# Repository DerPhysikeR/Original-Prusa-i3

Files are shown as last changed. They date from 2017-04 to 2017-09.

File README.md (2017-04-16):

# Replikeo Prusa i3 MK2S (Alpha: Not finished yet!)

This is an adaptation of the printed parts of the original Prusa i3 MK2S, to work with the parts included in the Prusa i3 kit from Replikeo.

Some parts like a new heated bed and an E3D V6 have to to be bought.

**Links**

 * Prusa Research website : http://prusa3d.com
 * Product page : http://shop.prusa3d.com/en/3d-printers/59-original-prusa-i3-mk2-kit.html
 * Build manual : http://manual.prusa3d.com/c/Original_Prusa_i3_MK2S_kit_assembly
 * Firmware : https://github.com/prusa3d/Prusa-Firmware

# Printing Instructions

Supports need for:
 - x-idler
 - y-corners

y-idler: Infill 100% or it will crack

More instructions will follow.

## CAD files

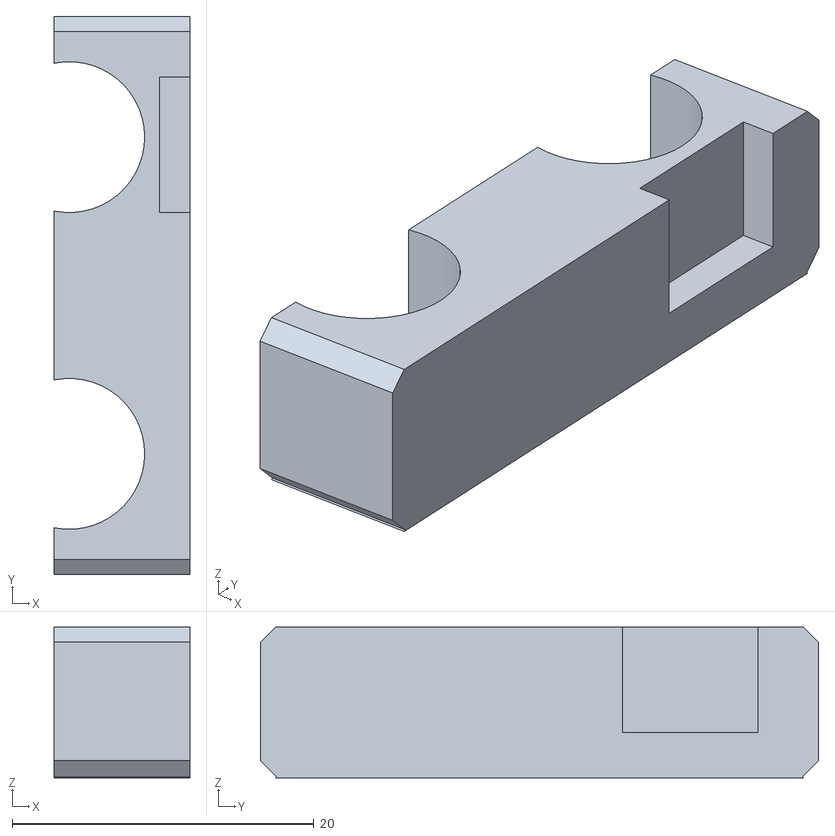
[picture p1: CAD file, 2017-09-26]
Printed-Parts/stl/Y-distance.stl
9.00 x 37.0 x 10.0

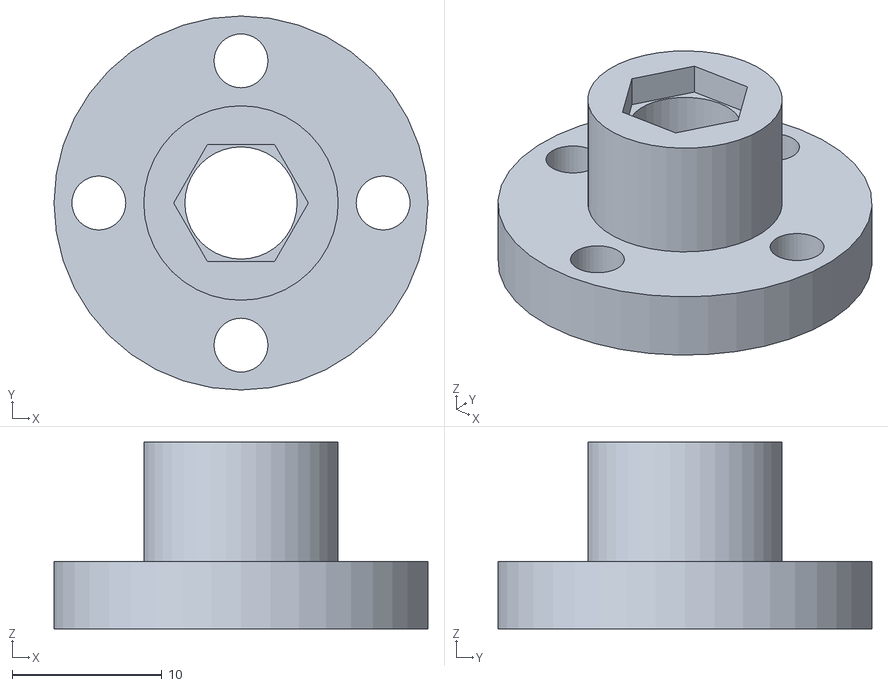
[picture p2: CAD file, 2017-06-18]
Printed-Parts/stl/z-axis-threaded-rod-adapter.stl
25.0 x 25.0 x 12.5

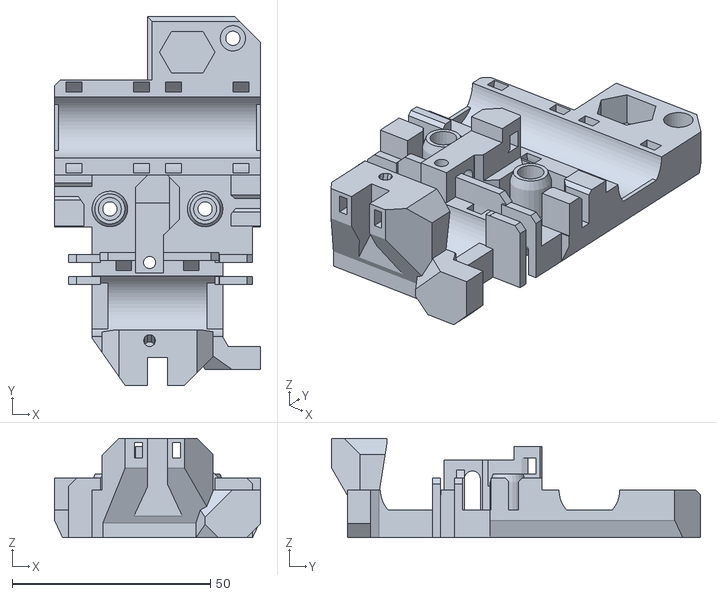
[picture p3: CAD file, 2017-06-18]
Printed-Parts/stl/x-carriage.stl
52.0 x 93.0 x 25.0

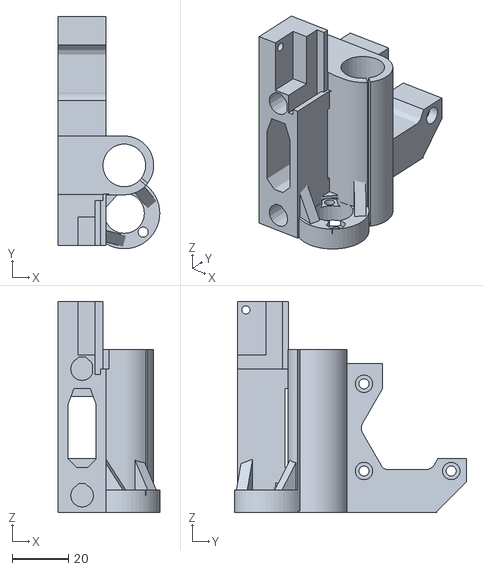
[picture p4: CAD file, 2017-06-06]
Printed-Parts/stl/x-end-motor.stl
36.1 x 82.6 x 75.0

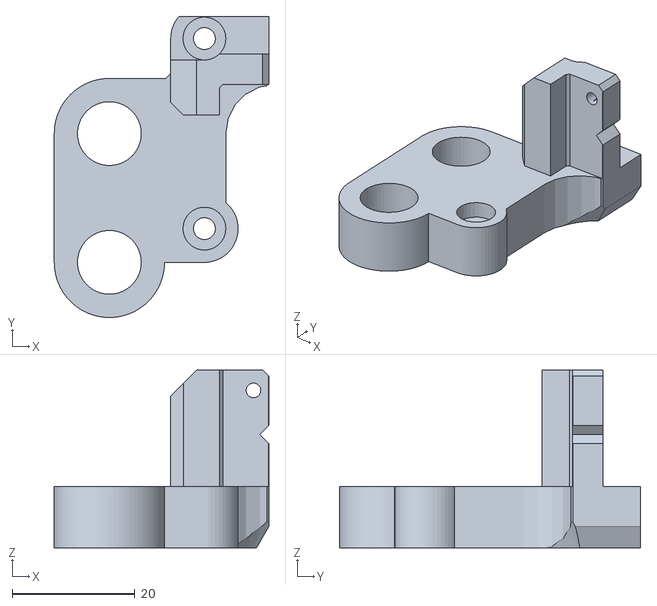
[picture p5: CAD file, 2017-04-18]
Printed-Parts/stl/y-motor.stl
35.0 x 49.1 x 29.0

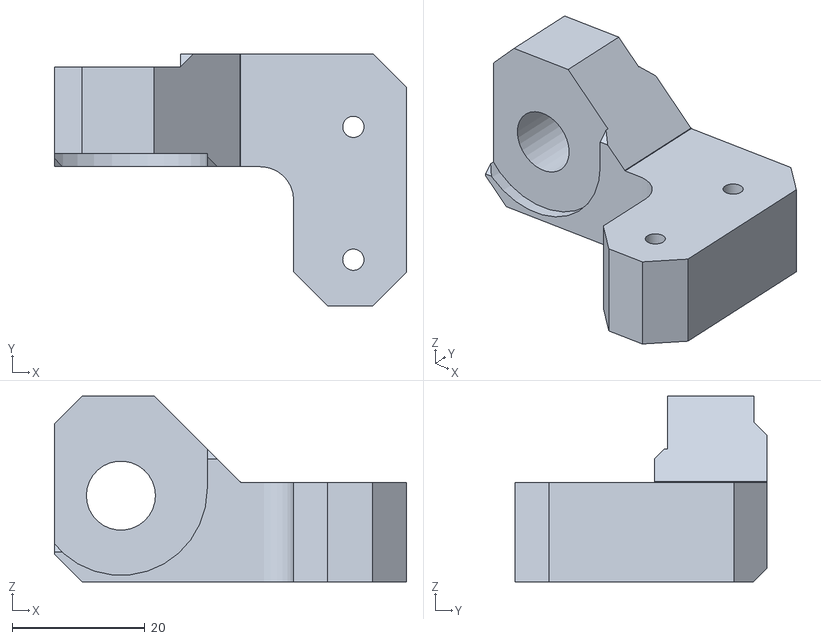
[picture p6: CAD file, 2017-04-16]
Printed-Parts/stl/PSU-Y-part.stl
53.0 x 38.0 x 28.0

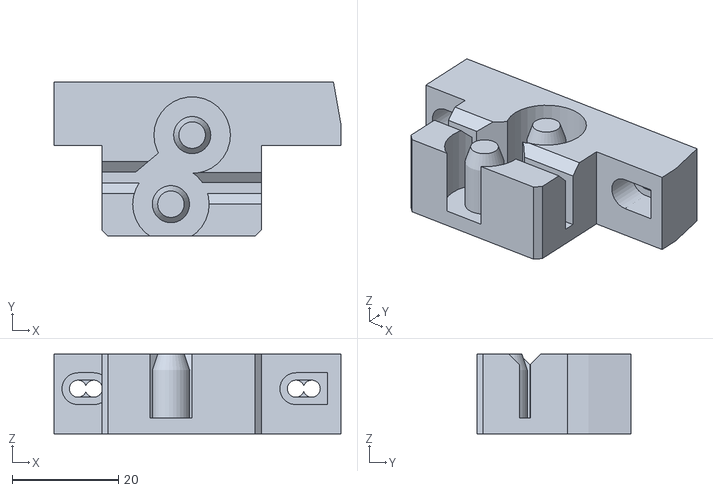
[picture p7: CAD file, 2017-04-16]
Printed-Parts/stl/y-belt-holder.stl
54.0 x 29.0 x 15.0

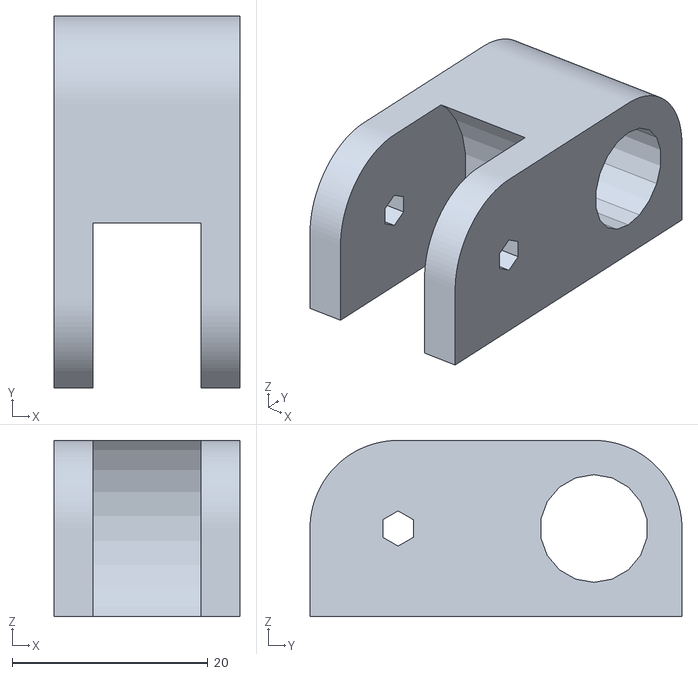
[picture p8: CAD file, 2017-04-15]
Printed-Parts/stl/y-idler.stl
19.0 x 38.0 x 18.0

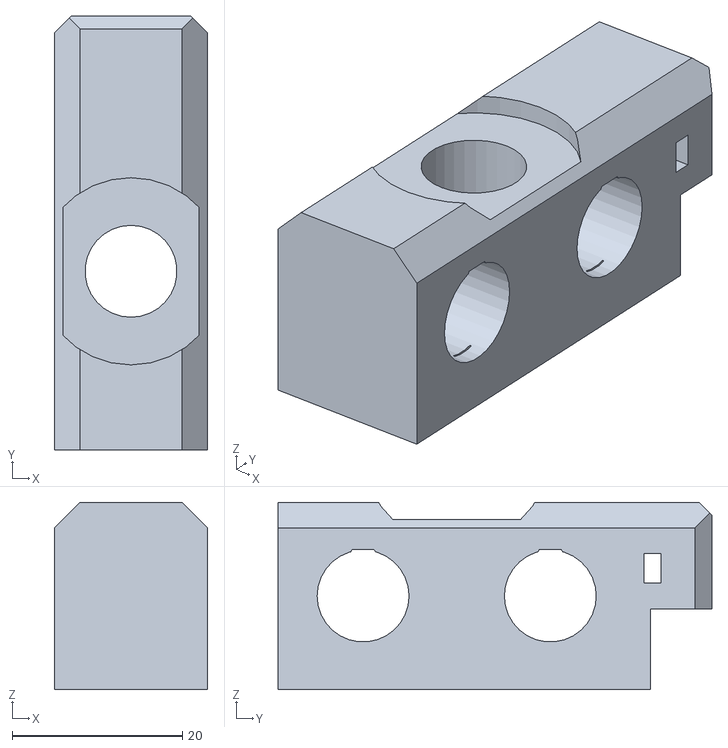
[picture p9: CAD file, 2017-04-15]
Printed-Parts/stl/y-corners.stl
18.0 x 51.0 x 22.0

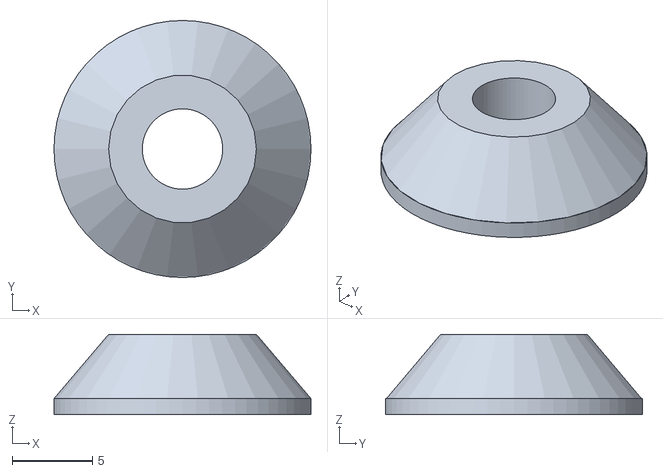
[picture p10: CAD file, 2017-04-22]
Printed-Parts/stl/z-screw-cover.stl
16.0 x 16.0 x 5.00

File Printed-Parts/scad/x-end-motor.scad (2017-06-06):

// PRUSA iteration3
// X end motor
// GNU GPL v3
// Josef Průša <iam@josefprusa.cz> and contributors
// http://www.reprap.org/wiki/Prusa_Mendel
// http://prusamendel.org

use <x-end.scad>

module x_end_motor_base(){
 x_end_base();
 translate(v=[-15,31,26.5]) cube(size = [17,44,53], center = true);
}

module x_end_motor_endstop_base(){
    translate([-23.5,-28.5,58]){
        difference(){
            // Base block
            cube([17,18.2,17]);
            // Nice edge
            /* translate([-1,5,20])rotate([-60,0,0])cube(30,30,30); */
            } 
        }
}

module support() {
     translate([-23.5,-28.5,49]){
          translate([13,0,0]) {
               translate([-.8,0,0]) cube([.8,16.1,5]);
          }
     }

}

module x_end_cutout() {
     translate([-23.5,-28.5,49]){
               translate([13,0,0]) {
                    translate([3,0,2]) cube([2,18.3,27]);
                    cube([2,16.1,27]);
                    translate([0,0,2]) cube([3,16.1,27]);
                    /* 13 is the real height of the endstop, but to make it printable a second cube with 20 is used */
                    translate([-5.9,0,7]) cube([7.9,10.1,13]);
                    translate([-5.9,0,7]) cube([7.9,10.1,20]);
                    /* translate([-20,0,23]) rotate([0, 90, 0]) cylinder(h=30, d=2.8, $fn=50); */
                    translate([-20,3,23]) rotate([0, 90, 0]) cylinder(h=30, d=3, $fn=10);
                    }
          }

}

module x_end_motor_endstop_holes(){
    translate([-23.5,-28.5,58]){
        translate([17/2,7.5,-3]){
            // Back screw hole for endstop
            translate([-4.75,0,0])cylinder(r=1,h=19,$fn=20);
            translate([-4.75,0,6])cylinder(r1=1, r2=1.5, h=2,$fn=20);
            // Front screw hole for endstop
            translate([4.75,0,0])cylinder(r=1,h=19,$fn=20);
            translate([4.75,0,6])cylinder(r1=1, r2=1.5, h=2,$fn=20);
            }
        }
}



module x_end_motor_holes(){
 x_end_holes();
 // Position to place
 translate(v=[-1,32,30.25]){
  // Belt hole
  translate(v=[-14,1,0]) cube(size = [10,46,22], center = true);
  // Motor mounting holes
  translate(v=[20,-15.5,-15.5]) rotate(a=[0,-90,0]) rotate(a=[0,0,90]) cylinder(h = 70, r=1.8, $fn=30);
  translate(v=[1,-15.5,-15.5]) rotate(a=[0,-90,0]) rotate(a=[0,0,90]) cylinder(h = 10, r=3.1, $fn=30);
  translate(v=[20,-15.5,15.5]) rotate(a=[0,-90,0]) rotate(a=[0,0,90]) cylinder(h = 70, r=1.8, $fn=30);
  translate(v=[1,-15.5,15.5]) rotate(a=[0,-90,0]) rotate(a=[0,0,90]) cylinder(h = 10, r=3.1, $fn=30);
  translate(v=[20,15.5,-15.5]) rotate(a=[0,-90,0]) rotate(a=[0,0,90]) cylinder(h = 70, r=1.8, $fn=30);
  translate(v=[1,15.5,-15.5]) rotate(a=[0,-90,0]) rotate(a=[0,0,90]) cylinder(h = 10, r=3.1, $fn=30);
  translate(v=[20,15.5,15.5]) rotate(a=[0,-90,0]) rotate(a=[0,0,90]) cylinder(h = 70, r=1.8, $fn=30);
  translate(v=[1,15.5,15.5]) rotate(a=[0,-90,0]) rotate(a=[0,0,90]) cylinder(h = 10, r=3.1, $fn=30);

  // Material saving cutout 
  translate(v=[-10,12,10]) cube(size = [60,42,42], center = true);

  // Material saving cutout
  translate(v=[-10,40,-30]) rotate(a=[45,0,0])  cube(size = [60,42,42], center = true);
  
 }
}

// Motor shaft cutout
module x_end_motor_shaft_cutout(){
    union(){
    difference(){
        translate(v=[0,32,30]) rotate(a=[0,-90,0]) rotate(a=[0,0,90]) cylinder(h = 70, r=17, $fn=6);
       
        translate(v=[-10,-17+32,30]) cube(size = [60,2,10], center = true);
        translate(v=[-10,-8+32,-15.5+30]) rotate(a=[60,0,0]) cube(size = [60,2,10], center = true); 
        translate(v=[-10,8+32,-15.5+30]) rotate(a=[-60,0,0]) cube(size = [60,2,10], center = true);
        
        
    }
    translate(v=[-30,25.2,-11.8 +30]) rotate(a=[0,90,0]) cylinder(h = 30, r=3, $fn=30);
    translate(v=[-30,19.05,30]) rotate(a=[0,90,0]) cylinder(h = 30, r=3.5, $fn=100);
}
}



module selective_infill()mirror([0,1,0]) translate([-50, -33, 0.6])
{ 
   difference()
    {
    union()
    {
        difference()
        {
        translate([50,50,0.6]) rotate([0,0,90]) cylinder( h=6, r=11.7, $fn=30);//0, 17, 0.6
        translate([50,50,-1]) rotate([0,0,90]) cylinder( h=10, r=11.5, $fn=30);
        }
        difference()
        {
        translate([50,50,0.6]) rotate([0,0,90]) cylinder( h=6, r=10.7, $fn=30); //0, 17, 0.6
        translate([50,50,-1]) rotate([0,0,90]) cylinder( h=10, r=10.5, $fn=30);
        } 
        difference()
        {
        translate([50,50,0.6]) rotate([0,0,90]) cylinder( h=6, r=9.9, $fn=30); //0, 17, 0.6
        translate([50,50,-1]) rotate([0,0,90]) cylinder( h=10, r=9.7, $fn=30);
        } 
        difference()
        {
        translate([50,50,0.6]) rotate([0,0,90]) cylinder( h=6, r=9, $fn=30); //0, 17, 0.6
        translate([50,50,-1]) rotate([0,0,90]) cylinder( h=10, r=8.8, $fn=30);
        } 
    }
    translate([57.5,50.5,-1]) rotate([0,0,45]) cube([8,10,9]); // front
    translate([52,30.5,-1]) rotate([0,0,45]) cube([10,20,20]);  // front angled
    translate([32,35.5,-1]) cube([8,30,9]); // inner horizontal
    }
   } 
   
 module reinforcement_selective_infill()
   {
    rotate([90,0,-15,]) translate ([-1.5, 8, 26])linear_extrude(height = 0.2) polygon( points=[[-2,0],[0,12],[8,0]] ); //bearings
    
    rotate([90,0,-50,]) translate ([8.5, 8, 1.4])linear_extrude(height = 0.2) polygon( points=[[0,0],[0,12],[8,0]] ); //body
    
    }
    
   
// Final part
module x_end_motor(){
 difference(){
     union(){
            x_end_motor_base();
            x_end_motor_endstop_base();
            
         }
  x_end_motor_shaft_cutout();
  x_end_motor_holes();
  /* x_end_motor_endstop_holes();       */
  x_end_cutout();
  selective_infill();
  reinforcement_selective_infill();
         
      /* translate([-12,-42,65]) rotate([-35,0,0])  rotate([0,0,45]) cube(10,10,10); */
      translate([-15,8.5,6]) rotate([90,0,0]) cylinder(h=5, r=5, $fn=30);   
      translate([-15,8.5,51]) rotate([90,0,0]) cylinder(h=5, r=5, $fn=30);   
      translate([-15,3.5,6]) rotate([90,0,0]) cylinder(h=3, r1=5, r2=4, $fn=30);   
      translate([-15,3.5,51]) rotate([90,0,0]) cylinder(h=3, r1=5, r2=4, $fn=30); 
 }
}

union() {
  x_end_motor();
  support();
}

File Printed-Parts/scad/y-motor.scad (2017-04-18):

// PRUSA iteration3
// Y motor mount
// GNU GPL v3
// Josef Průša <iam@josefprusa.cz> and contributors
// http://www.reprap.org/wiki/Prusa_Mendel
// http://prusamendel.org

//include <configuration.scad>

module y_motor_base() {
  union() {
    // Motor holding part
    translate(v = [29,-21+50,0]) {
      difference() {
        union() {
          translate(v = [-21+4.5,0,5]) cube(size = [9,31,10], center=true);
          translate(v = [-15.5,-15.5,0]) cylinder(h = 10, r=5.5, $fn=50);
          translate(v = [-15.5,+15.5,0]) cylinder(h = 10, r=5.5, $fn=50);
          translate([-21,7,0]) rotate([0,0,45]) cube([2, 2, 10]);

          //end stop
          /* translate(v = [-10.5,+15.5,0]) cylinder(h = 12, r=5.5, $fn=50); */
          translate([-12,0,0]) cube([7, 15, 10]);
          translate([-16,15,0]) cube([11, 4.1, 10]); //top of endstop mount //here
          translate([-21+6,8,0]) cube([12-2, 5, 29]);
          translate([-21,8-5,0]) cube([8, 10, 29]);
          translate([-21+9.5-2,7,0]) rotate([0,0,45]) cube([2, 2, 29]);
          // Joins motor holder and rod plate
          translate(v = [-31,-21,0]) cube(size = [16,30,10]);
        }
          //selective infill
          translate([-14.5,5,0.3]) cube([0.1,5.5,27]);
          translate([-16.5,5,0.3]) cube([0.1,5.5,27]);
          translate([-18.5,5,0.3]) cube([0.1,5.5,25]);
          translate([-10,9,1]) cube([0.1,3,26.3]);
          translate([-8,9,6]) cube([0.1,3,21.3]);
      }
    }
  }
  // Front holding part
  hull() {
    translate(v = [-2,8,0]) cylinder(h = 10, r=9, $fn=80);
    translate(v = [-2,29,0]) cylinder(h = 10, r=9, $fn=80);
  }
}

module y_motor_holes() {
  translate(v = [29,-21+50,0]) {
    // Screw head holes
    translate(v = [-15.5,-15.5,-1]) cylinder(h = 10, r=1.8, $fn=20);
    translate(v = [-15.5,+15.5,-1]) cylinder(h = 10, r=1.8, $fn=20);
    // Clearance for motor neck
    translate(v = [0,0,-1]) cylinder(h = 6, d1=24.2, d2=18.2, $fn=50);
    // Screw holes
    translate(v = [-15.5,-15.5,7]) cylinder(h = 7, r=3.5, $fn=30);
    translate(v = [-15.5,+15.5,7]) cylinder(h = 25, r=3.5, $fn=30);
  }

  translate(v = [-2,8,-1]) cylinder(h = 12, r=5.2, $fn=50);
  translate(v = [-2,29,-1]) cylinder(h = 12, r=5.2, $fn=50);

  //endstop
  translate([25,29,0])  cylinder(h = 29, r=8, $fn=20);

  /* M3 core diameter~=2.4mm */
  /* hole distance from front edge=3.1 */
  fed = 2.5;
  side_dist = -3.3 + 10;
  height_difference = 5.9;
  translate([24-fed,45+height_difference,side_dist]) rotate([90,0,0]) cylinder(h = 10, r=1.2, $fn=20);
  translate([24-fed,42.2+height_difference,side_dist]) rotate([90,0,0]) cylinder(h = 2, r1=1.7, r2=1.2, $fn=20);

  /* center distance endstop holes=19mm */
  cdist = 19;
  translate([24-fed,45,side_dist+cdist]) rotate([90,0,0]) cylinder(h = 10, r=1.2, $fn=20);
  translate([24-fed,42.2,side_dist+cdist]) rotate([90,0,0]) cylinder(h = 2, r1=1.7, r2=1.2, $fn=20);
  /* side distance for first hole = 3.7 */

  // endstop corner cutout
  translate([-10,30,28]) rotate([0,45,0]) cube([15, 19, 20]);
  translate([-1,41,10])  cube([15, 5, 19]);
  translate([27,33,0]) rotate([0,0,45]) cube([5, 5, 28]);
  translate([7,28,10.01]) rotate([0,0,45]) cube([5, 5, 28]);

  translate([22,32,0]) rotate([0,30,0]) cube([8, 20, 18]);
  translate([24.5-2,32,18.5]) rotate([0,45,0]) cube([3, 20, 3]);

  translate([23,32,29]) rotate([0,45,0]) cube([5, 20, 5]);

  // cut off top of end-stop mount
  translate([0,48.1,0]) cube([100,100,100]);
}

// Final part
module y_motor() {
  difference() {
    y_motor_base();
    y_motor_holes();
  }
}

y_motor();

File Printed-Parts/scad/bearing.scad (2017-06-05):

// PRUSA iteration3
// Bearing holders
// GNU GPL v3
// Josef Průša <iam@josefprusa.cz> and contributors
// http://www.reprap.org/wiki/Prusa_Mendel
// http://prusamendel.org

use <polyholes.scad>

bearing_diameter = 14.90;

module horizontal_bearing_base(bearings=1){
 translate(v=[0,0,6]) cube(size = [24,8+bearings*25,12], center = true);	
}
module horizontal_bearing_holes(bearings=1){
 cutter_lenght = 10+bearings*25;
 one_holder_lenght = 8+25;
 holder_lenght = 8+bearings*25;
 
 // Main bearing cut
 difference(){
  translate(v=[0,0,12]) rotate(a=[90,0,0]) translate(v=[0,0,-cutter_lenght/2]) cylinder(h = cutter_lenght, r=(bearing_diameter/2)+0.2, $fn=50);
  // Bearing retainers
  translate(v=[0,1-holder_lenght/2,3]) cube(size = [24,6,8], center = true);
  translate(v=[0,-1+holder_lenght/2,3]) cube(size = [24,6,8], center = true);
 }
 
 // Ziptie cutouts
 ziptie_cut_ofset = 0;
 for ( i = [0 : bearings-1] ){
  // For easier positioning I move them by half of one 
  // bearing holder then add each bearign lenght and then center again
  translate(v=[0,-holder_lenght/2,0]) translate(v=[0,one_holder_lenght/2+i*25,0]) difference(){
   union(){
    translate(v=[0,2-8.5,12]) rotate(a=[90,0,0]) translate(v=[0,0,0]) cylinder(h = 4, r=11.5, $fn=50);
    translate(v=[0,2+8.5,12]) rotate(a=[90,0,0]) translate(v=[0,0,0]) cylinder(h = 4, r=11.5, $fn=50);
   }
   translate(v=[0,12,12]) rotate(a=[90,0,0]) translate(v=[0,0,0]) cylinder(h = 24, r=9, $fn=50);
  }
 }
 
}

module horizontal_bearing_test(){
 difference(){
  horizontal_bearing_base(1);
  horizontal_bearing_holes(1);
 }
 translate(v=[30,0,0]) difference(){
  horizontal_bearing_base(2);
  #horizontal_bearing_holes(2);
 }
 translate(v=[60,0,0]) difference(){
  horizontal_bearing_base(3);
  horizontal_bearing_holes(3);
 }
}



thinwall = 3;
bearing_size = bearing_diameter + 2 * thinwall;

module vertical_bearing_base(){
 translate(v=[-2-bearing_size/4,0,29]) cube(size = [4+bearing_size/2,bearing_size,58], center = true);
 cylinder(h = 58, r=bearing_size/2, $fn = 90);
}

module vertical_bearing_holes(){
  translate(v=[0,0,-1]) poly_cylinder(h = 62, r=(bearing_diameter/2));
  translate(v=[0,0,-0.1]) cylinder(r1=(bearing_diameter/2)+0.7,r2=(bearing_diameter/2), h=0.5);
  rotate(a=[0,0,-40]) translate(v=[bearing_diameter/2-2.9,-0.5,0.5]) cube(size = [thinwall*2,1,62]);

}

//difference(){
//vertical_bearing_base();
vertical_bearing_holes();
//}
//horizontal_bearing_test();
//horizontal_bearing_base(1);
//horizontal_bearing_holes(1);

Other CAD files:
Printed-Parts/scad/PSU-Y-part.scad
Printed-Parts/scad/Y-distance.scad
Printed-Parts/scad/x-carriage.scad
Printed-Parts/scad/y-belt-holder.scad
Printed-Parts/scad/y-corners.scad
Printed-Parts/scad/y-idler.scad
Printed-Parts/scad/z-axis-threaded-rod-adapter.scad
Printed-Parts/scad/z-screw-cover.scad

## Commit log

2017-04-15 Adapted y-corners to 10mm threaded rods
    [y-corners.scad]
2017-04-15 Formatting in `y-corners`
    [y-corners.scad]
2017-04-15 Updated y-corners.stl
    [y-corners.stl]
2017-04-15 Adapted y-idler to 10mm threaded rod
    [y-idler.scad, y-idler.stl]
2017-04-15 Formatting of `y-motor.scad`
    [y-motor.scad]
2017-04-15 Adapted `y-motor` to 10mm threaded rods
    [y-motor.scad]
2017-04-15 Fixed position of upper hole for threaded rod
    New corners increase the distance between the top threaded rod and the smooth
    rod by 1mm.
    [y-motor.scad]
2017-04-15 Adapted y-motor to new endstops and updated stl
    [y-motor.scad, y-motor.stl]
2017-04-15 Fixed y-endstop mount height
    [y-motor.scad, y-motor.stl]
2017-04-16 Adapted y-belt-holder to new endstop
    [y-belt-holder.scad, y-belt-holder.stl]
2017-04-16 Fixed unstable endstop mount
    [y-motor.scad]
2017-04-16 Fixed position of threaded rod holes because of washer diameter
    [y-motor.scad, y-motor.stl]
2017-04-16 Updated README with a few printing instructions and intro.
2017-04-16 Adapted PSU-y-part to 1mm lower threaded rod
    [PSU-Y-part.scad, PSU-Y-part.stl]
2017-04-18 Added clearance for motor neck
    [y-motor.scad, y-motor.stl]
2017-04-22 Adapted x-end-motor to different endstops > no z-axis coupler usable
    [x-end-motor.scad, x-end-motor.stl]
2017-04-22 Adapted z-screw-cover to 5mm motor axis
    [z-screw-cover.scad, z-screw-cover.stl]
2017-06-05 Fixed x-endstop mount hole diameter
    [x-end-motor.scad]
2017-06-05 Deeper clearance for x-endstop switch
    [x-end-motor.scad]
2017-06-05 Thicker holding lip for x-endstop
    [x-end-motor.scad]
2017-06-05 Tighter bearing tolerances
    [bearing.scad]
2017-06-06 Add support to thin walled surface behind x-endstop
    [x-end-motor.scad, x-end-motor.stl]
2017-06-18 Add adapter for M5 threaded z-rod
    [z-axis-threaded-rod-adapter.scad]
2017-06-18 Adapted x-carriage to .2mm thicker belt
    [x-carriage.scad]
2017-06-18 Remove selective infill in x-carriage; 100% infill now necessary
    A part of the x-carriage broke off when mounting the x-belt.
    Adapting the x-carriage to the slightly thicker belt and using 100% infill,
    should solve this problem.
    [x-carriage.scad]
2017-06-18 Update x-carriage and z-axis-threaded-rod-adapter .stl files
    [x-carriage.stl, z-axis-threaded-rod-adapter.stl]
2017-09-26 Adapted y-distance to 10mm threaded rods
    [Y-distance.scad]
2017-09-26 Updated y-distance stl
    [Y-distance.stl]
